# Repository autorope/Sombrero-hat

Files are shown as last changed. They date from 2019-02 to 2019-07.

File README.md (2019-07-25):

# Sombrero-hat
This is the board files for the Sombrero hat.  The Sombrero hat should just work with the most recent donkey software, however if you are hacking on it. The following Pins will matter to you:

* PMW OUT (0-5) - PCA Channel 2-7
* I2C.SDA - BCM[0]
* I2C.SCL - BCM[1]
* LED.0 - BCM[13]
* LED.2 - BCM[19]
* GPIO.0 - BCM[16]
* GPIO.1 - BCM[20]
* GPIO.2 - BCM[21]
* Enable BCM [26]

The most important one, is that the hat has an enable pin - this has to be pulled low in order for the car to work.  This is always a nice feature for all robots as it can act as a kill switch.  The LEDs need to be driven low as well in order to work.

Ths Sombrero buck converter is a 3A converter and will work with all Rasberry Pis including the pi4

For more information on the hat watch this [video](https://youtu.be/vuAXdrtNjpk)

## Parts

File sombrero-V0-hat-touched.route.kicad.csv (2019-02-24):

Id | Designator | Package | Quantity | Designation | Supplier and ref
1 | U2 | SOP65P640X110-28N | 1
2 | D1,D0,D2 | LEDSC16080X80 | 3
3 | U0 | QFN50P300X300X100-16 | 1
4 | R4,R0,R1,R2,R3,R5,R6,R7,R8 | RESC1005X35 | 9
5 | ,,, | mounting-hole-pkg | 4
6 | C0,C1,C3,C5 | CAPC1005X55 | 4
7 | , | XT-60-female-pkg | 2
8 |  | pin-header-pkg$3 | 1
9 |  | pin-header-pkg$4 | 1
10 | U1 | d-pak-5-pkg | 1
11 |  | pin-header-pkg$2 | 1
12 | S0 | SW-JS102011SAQN-pkg | 1
13 | C2,C4 | CAPC3216X160 | 2
14 | , | pin-header-pkg | 2
15 | L0 | INDM560520X300 | 1
16 |  | raspi-3B+-pkg | 1
17 | , | HOLE | 2

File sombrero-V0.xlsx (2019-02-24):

Quantity | Reference Designators | Manufacturer | Manufacturer Part Number
1 | R2 | Yageo | RC0402JR-071K2L
2 | J0 J1 | HexTronics | XT-60
1 | J4 | TE Connectivity | Generic 7x1 pin header
1 | R4 | Yageo | RC0402JR-07180KL
4 | H0 H1 H2 H3 | NONE | NONE
1 | J2 | TE Connectivity | Generic 5x1 pin header
2 | R0 R3 | Yageo | RC0402JR-074K7L
1 | U1 | Infineon | BTS6133DAUMA1
1 | U0 | Texas Instruments | TLV62130A
2 | J5 J6 | TE Connectivity | Generic 3x1 pin header
2 | R5 R7 | Yageo | RC0402JR-07220RL
1 | C1 | Yageo | CC0402MRX7R8BB104 | 0.1 | 20 | 16
1 | J3 | TE Connectivity | Generic 4x1 pin header
1 | L0 | Abracon | ASPI-0530HI-2R2M-T2
1 | C0 | Yageo | CC0402JRX7R8BB681 | 0.00062 | 5 | 16
1 | R6 | Yageo | RC0402JR-07910KL
3 | D0 D1 D2 | Lite-On | LTST-C190GKT
1 | C4 | Yageo | CC1206KKX5R8BB226
1 | S0 | C&K | JS102011SAQN
1 | R8 | Yageo | RC0402JR-0710KL
1 | C5 | Yageo | CC0402KRX5R6BB105
1 | C2 | Yageo | CC1206KKX5R8BB106
1 | U2 | NXP | PCA9685PW
1 | U3 | Particle | particle-electon
1 | R1 | Yageo | RC0402JR-07100KL
1 | C3 | Yageo | CC0402KRX7R6BB104

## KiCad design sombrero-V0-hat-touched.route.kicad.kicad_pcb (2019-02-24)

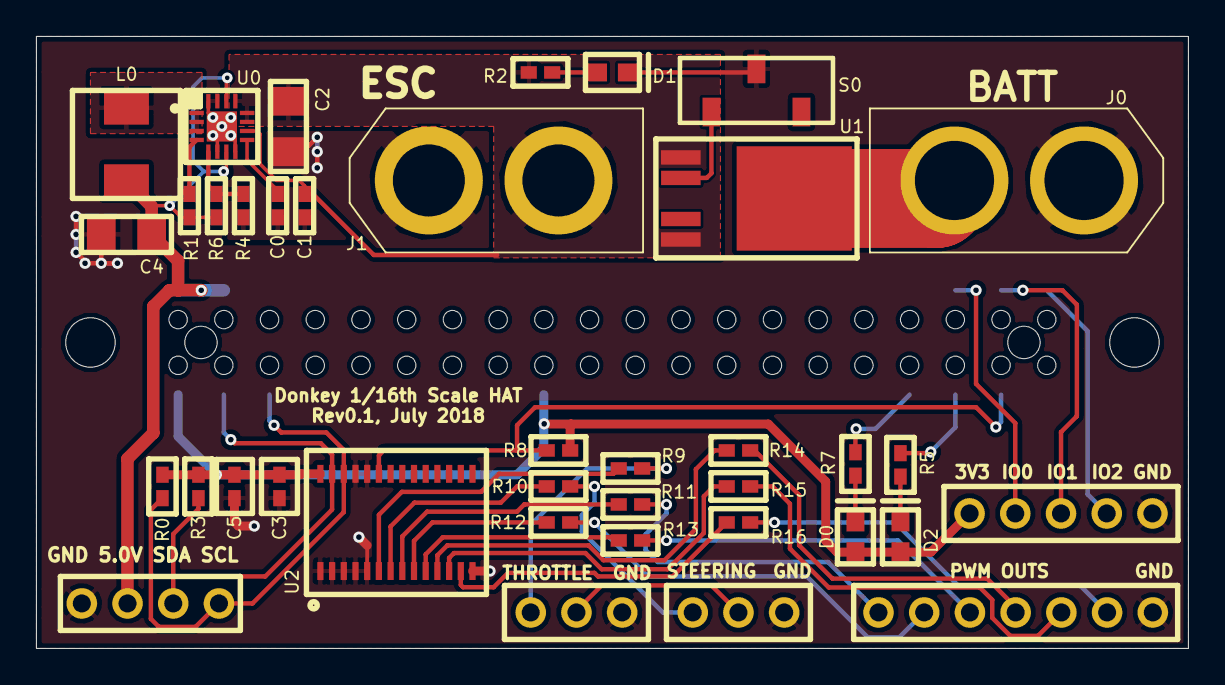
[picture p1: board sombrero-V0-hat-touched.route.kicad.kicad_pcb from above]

Board: 2 copper layers, 64.0 x 34.0 mm, 34 parts (1 on the bottom side), 26 nets.

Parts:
C0, C1, C3, C5: CAPC1005X55
C2, C4: CAPC3216X160
D0, D1, D2: LEDSC16080X80
J0: XT-60-male-pkg
J1: XT-60-female-pkg
J7: raspi-3B+-pkg
L0: INDM560520X300
R0, R1, R2, R3, R4, R5, R6, R7, R8, R9, R10, R11, R12, R13, R14, R15, R16: RESC1005X35
S0: SW-JS102011JCQN-pkg
U0: QFN50P300X300X100-16
U1: d-pak-5-pkg
U2: SOP65P640X110-28N

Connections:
conn-XT-60-pass-0-inst_conn_noname548: S0.0, U1.1
conn-XT-60-pass-0-inst_conn_noname550: D1.0, R2.1
conn-XT-60-pass-0-inst_conn_noname552: J0.1, U1.2
dio: J7.32, R7.0
dio$2: J7.34, R5.0
gnd: C0.1, C1.1, C2.1, C3.0, C4.1, C5.0, D1.1, J0.0, J1.0, J7.5, J7.8, J7.13, J7.19, J7.24, J7.29, J7.33, J7.38, R4.1, S0.1, U0.5, U0.7, U0.14, U0.15, U0.16, U2.0, U2.1, U2.2, U2.3, U2.4, U2.13, U2.23, U2.24
led$2_noname732: D2.1, R5.1
led_noname732: D0.1, R7.1
noname764_scl: J7.4, R0.0, U2.25
noname764_sda: J7.2, R3.0, U2.26
pi_noname681: C0.0, U0.8
pi_noname682: L0.0, U0.0, U0.1, U0.2
pi_noname683: R1.1, U0.3
pi_noname684: R4.0, R6.1, U0.4
pow-3v3_pos: C3.1, C5.1, D0.0, D2.0, J7.0, J7.16, R0.1, R3.1, R8.0, U2.27
pow-5v0_pos: C4.0, J7.1, J7.3, L0.1, R1.0, R6.0, U0.6, U0.13
pow-7v4_pos: C1.0, C2.0, J1.1, R2.0, U0.9, U0.10, U0.11, U0.12, U1.0, U1.4
servo-connectors_noname564: R9.0, U2.5
servo-connectors_noname565: R10.0, U2.6
servo-connectors_noname574: R11.0, U2.7
servo-connectors_noname575: R12.0, U2.8
servo-connectors_noname576: R13.0, U2.9
servo-connectors_noname577: R14.0, U2.10
servo-connectors_noname578: R15.0, U2.11
servo-connectors_noname579: R16.0, U2.12
servo-connectors_pwm-drv_noname594: J7.36, R8.1, U2.22

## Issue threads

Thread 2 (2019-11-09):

kicad schematic is empty

robomaniac, 2019-11-09:
I tried to open the sch file in kicad and there is nothing, it's empty.
I can open the PCB and the library.

Could you please post a PDF of the schematic

thank you

adammconway, 2019-11-09:
Sorry, there is no schematic - long story but this board was developed by an application that uses code as the schematic.  What were you wondering?  Maybe I can answer it.

robomaniac, 2019-11-10:
I would like to design my own sombrero hat. I think what you did is great. I am thinking about making a PCB that is a structural part of the RC frame with other features build in.

I have the BOM, so I know the components, got the pinout. Have the PCB so I can figure things out. A schematic would of been simpler and faster.
